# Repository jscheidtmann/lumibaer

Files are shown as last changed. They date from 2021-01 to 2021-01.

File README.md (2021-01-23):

# lumibaer
Program for controlling a enhanced version of a Flötotto "Lumibär"

Status: in development

# Pimping the Lumibär

The Lumibär is ca. 40 cm high, formed like a bear and was originally was designed and developed by FLÖTOTTO (AFAICT) with a 12V halogen light. Nowadays, a LED-version is sold with a remote, which allows to set the color. 

As we wanted to have a rather unique version, I set out to create a rather nerdy version of it and am sharing my build here. 

Features:

* Uses an Arduino Nano with ESP8266 for WiFi connectivity (aka. Pretzelboard or NanoESP)
* Two Adafruit 16 Neopixel Rings for blinkenlights
* A button was added to enable a hands-on on/off and color selection.
* Supports various different modes:
    * **Single color mode**: acts as a normal light, with a color of your choosing.
	* **Sweep mode**: Transition between two colors.
	* **Lighthouse mode**: Turn your Lumibär into your favourite lighthouse by entering the ligth characteristic.
	* Optionally use different front and back colors.
	
As our Lumibär is opaque white, we refrain from supporting movements or using single LED patterns. 

# Circuitry

The parts used:

| Count | Part | Comment |
|---|---|---|
| 1x | NanoESP | aka Pretzelboard, an Arduino Nano + ESP8266 on a single PCB |
| 2x | 16 Neopixel Ring | WS2812B, must fit through hole in bottom |
| 1x | Button Switch | color to your liking |
| 1x | 470Ω Resistor | recommended by Adafruit in Neopixel tutorial |
| 1x | 1000 µF Capacitator | recommended by Adafruit in Neopixel tutorial | 
| 1x | Power Supply | 5V output, at least 2A |
| 5x | Dupont terminals | for connecting wires with the Arduino |
| | cable binders | fixing the power cable |
| | heat-shrink tubing  | avoid short circuits |

The parts are connected like this:

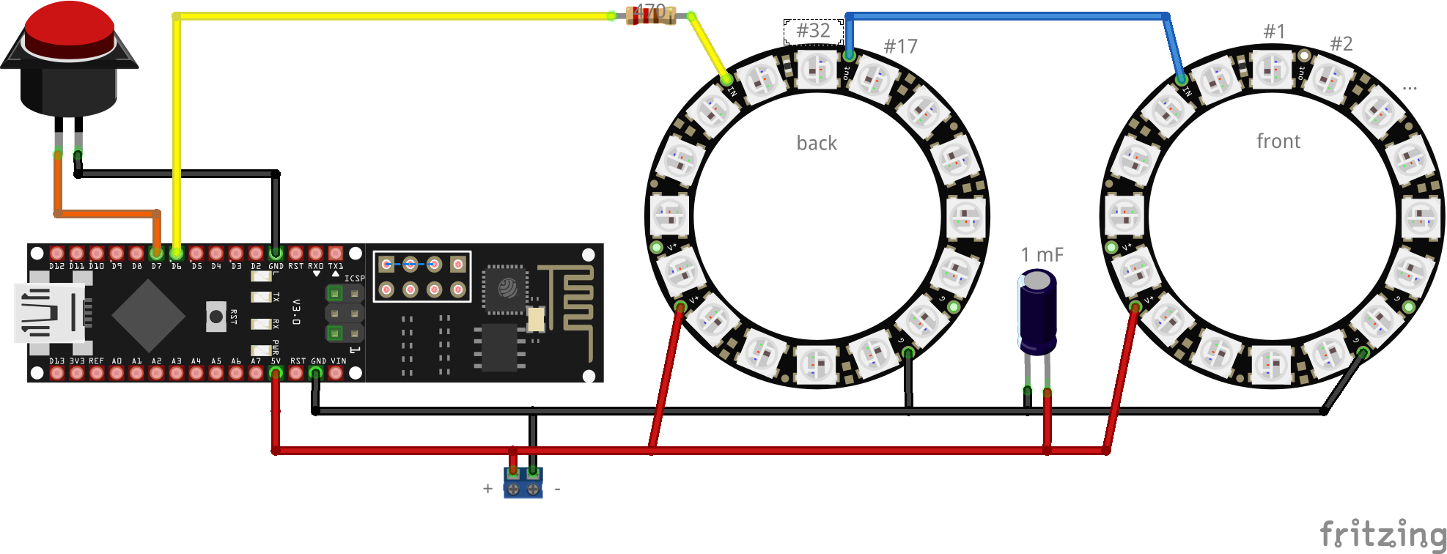
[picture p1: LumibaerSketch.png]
Fritzing circuit diagram Fritzing Circuit Diagram for Lumibär


Notes:

* The power supply has to be connected to the "screw terminal" at the bottom of the sketch
* The capacitator prevents damaging the pixel through the first current onrush, when the device is powered.
* The resistor prevents damaging the first pixel by spikes on the data line
* Both previous measure have been recommended in the [Adafruit Neopixel Überguide](https://learn.adafruit.com/adafruit-neopixel-uberguide/basic-connections)
* LED numbering implies how to mount the pixel rings in the holder (see below - lowest numbered pixel at top position), if you mount them differently, you may have to change some code.

--- W A R N I N G ---

When programming the Lumibaer, first power the device using the power supply, then connect the USB. If all 32 LEDs are set to full white, each LED draws approximately 60 milliamps, so in total a current of 1.9A is drawn, which is a) more than the Arduino is able to deliver and which b) might be more than the USB port of your computer is able to sustain. You have been warned!

# Holder

I 3D-printed the holder from white PLA on a Flashforge Finder. You can find the design at [onshape.com](https://cad.onshape.com/documents/3edbe17af1ac7154b36a21e5/w/be9cdfd852b25ba857e68c3f/e/f320dc2e18de69cdc695974b), the STL is also part of this repository. 

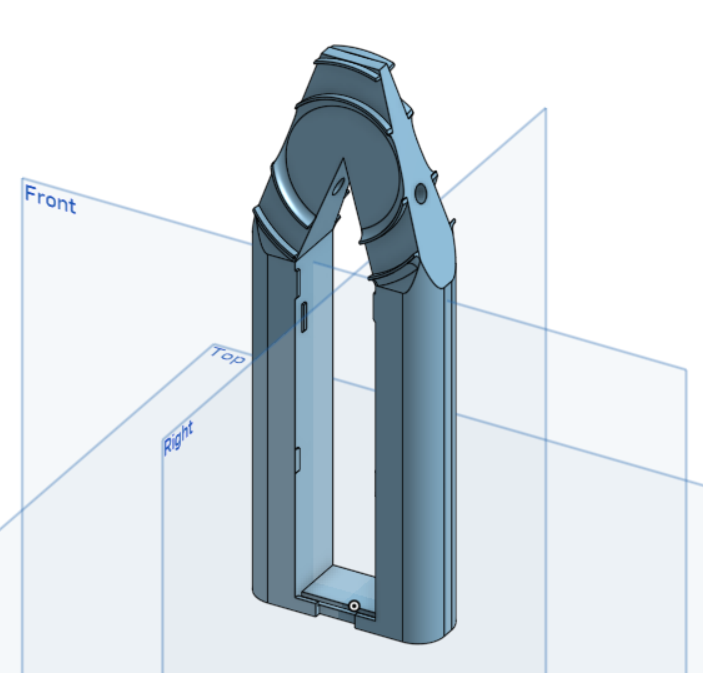
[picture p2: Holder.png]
Holder for Lumibaer isoscale rendering of the holder from onshape


Make sure that your printer's tolerances match your parts. In order to do this, print some prototypes to see, if:

1) The part fits on the metal rods holding it inside the Lumibär. Print the lowest 1 cm of the model. 
2) The Neopixel Rings fit into the holder (you have to press slightly, to get them in and fixed). Print the top part of the model.
3) Also check that the NanoESP fits into the middle opening (see below)

Only then print the full model

If scaling the model does not work and you need to change the design, here are some hints:

* The size of the holes (where the metal rods go) is in "Skizze 1"
* The circles defining the shape, where the Neopixel-rings go are defined in "Skizze 7".

# Assembly Instructions

1) Press in the two Neopixel-rings onto the holder, so that all terminals are still accessible and you can solder the wires
2) Put in the Arduino into the holder by inserting the ESP end at the top between the two protrusions, then force press it into place between the two sides. You may want to use a cutter knive to remove some of the protusions, so that it's easier to insert the Arduino
3) Solder the resistor onto the back facing D_IN port
4) Cut the power cord (5V) coming from the power supply and solder the capacitator in between the wires. Watch for the correct polarity, if you're using an electrolyte capacitator
5) Solder further power cables onto the pins of the capacitator
6) Prevent short circuits by using heat-shrink tubing
7) Fix the power cord to one of the metal rods using cable binders. Fix it two times, leaving some extra wire for protection against pulling out the wire.
8) Solder the remaining wires to the neopixel rings, using the holes in the holder for routing wires.
9) Attach Dupont-terminals to the wires going to be connected to the Arduino
10) Connect the wires to the Arduino
11) Connect the Arduino to your PC using an USB cable
12) If your Arduino features a blue power led, you should remove it (optional)

# Library Installations & Tests & Software Installation

Install the `Adafruit Neopixel` Library into your Arduinno IDE using the Tools -> Manage Libraries ... menu entry. For controlling the ESP part, download the [NanoESP library](https://iot.fkainka.de/library) (German site) or directly from [GitHub](https://github.com/FKainka/NanoESP).

In order to be able to upload sketches to the NanoESP, I had to choose Board "Arduino Nano" and Processor "ATmega328P (old bootloader)". You might need to choose a different setting, depending on how old your NanoESP is or wether your updated the firmware.

Then open and run the "strandtest" example from File -> Examples -> Adafruit NeoPixel. It should work out of the box. If it doesn't, check if the D_IN is connected to the right pin in the Arduino. You can then open the "test.ino" sketch from this project. It is basically a modified version of the strandtest program, which in addition switches the onboard LED, whenever the button switch is pressed and reorders the leds in the strip to make it easier to program later on. Check that the front ring is run through clockwise and back ring is run through conter clockwise. If that is not the case, check `pinTranslate()`.

If all is working well, define your network credentials in `credentials.h` and then compile and upload the `lumibaer.ino` sketch.

# Manual

## Initial State

When the Lumibär is connected to power, it tries to connect to the local WiFi, that you configured. If this is successful, the Lumibär flashes once in green. If it was unsuccessful, it flashes once in red. 

## Using the button

Pressing the button shortly switches the Lumibär on or off. The initial color is White (at full brightness). 
When switching on, hold the button and the Lumibär will cycle through colors. Just release the button, if the color is to your liking. After a color is selected, press the button shortly to switch the Lumibär on or off.

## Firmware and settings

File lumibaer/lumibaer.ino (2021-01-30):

/**
 * Lumibaer
 * 
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
 * 
 */

// Blinkenlights ---------------------------------------------

#include <Adafruit_NeoPixel.h>

// Which pin on the Arduino is connected to the NeoPixels?
#define LED_PIN    6

// How many NeoPixels are attached to the Arduino?
#define LED_COUNT 32

// Declare our NeoPixel strip object:
Adafruit_NeoPixel strip(LED_COUNT, LED_PIN, NEO_GRB + NEO_KHZ800);
// Argument 1 = Number of pixels in NeoPixel strip
// Argument 2 = Arduino pin number (most are valid)
// Argument 3 = Pixel type flags, add together as needed:
//   NEO_KHZ800  800 KHz bitstream (most NeoPixel products w/WS2812 LEDs)
//   NEO_KHZ400  400 KHz (classic 'v1' (not v2) FLORA pixels, WS2811 drivers)
//   NEO_GRB     Pixels are wired for GRB bitstream (most NeoPixel products)
//   NEO_RGB     Pixels are wired for RGB bitstream (v1 FLORA pixels, not v2)
//   NEO_RGBW    Pixels are wired for RGBW bitstream (NeoPixel RGBW products)

/**
 * Translate pin 
 */
int pinTranslate(int pin) {
  const int translation [] = { 
    // Front Ring, starting from 12 o'clock position, clockwise
    29, 28, 27, 26, 25, 24, 23, 22,  
    21, 20, 19, 18, 17, 16, 31, 30,
    // Back Ring, starting from one next to 12 o'clock position, counter clockwise
    13, 14, 15,  0,  1,  2,  3,  4,  
     5,  6,  7,  8,  9, 10, 11, 12, 
  };

  return translation[pin];
}


// ESP WiFi / Server Lib ---------------------------------------------------

// This is the library supplied by F. Kainka with the Pretzel Board. It is rather old and HTTP is rather limited.
#include <NanoESP.h>
#include <NanoESP_HTTP.h>

/**
 * define two string constants: 
 * WIFI = SSID of your router 
 * PASSWORD
 */
#include "credentials.h"

NanoESP nanoesp = NanoESP();
NanoESP_HTTP http = NanoESP_HTTP(nanoesp); 

// LED & Switch ------------------------------------------------------------

// Standard onboard LED on an Arduino Nano
#define ONBOARD_LED 13

// The switch button is connected to which pin?
#define SWITCH 7

// Switch Press must be detected this many milliseconds at least, to count as press.
#define SWITCH_THRESHOLD 50 

// Long press must be at least this long
// (should be at least two times SWITCH_THRESHOLD, see buttonDownDetected() )
#define SWITCH_LONGTHRESHOLD 2000

// Increment applied, when changing colors. 
// This is a prime on purpose.
#define SINGLE_INCREMENT 51

// Time (ms) waited when rotating colors
// (default value)
#define ROTATE_WAIT 50

// Time (ms) for Morse wait
// Short (.) = this time, long (-) = 3x this time.
// applies also to breaks between . and -, and words (long)
#define MORSE_WAIT 300

// Default Brightness 0-255
#define DEFAULT_BRIGHTNESS 50

// Globals -----------------------------------------------------------------

/**
 * Variable to enable debug output on the serial monitor.
 */
boolean debug_out = true;

/**
 * last time, a button down was detected
 * 
 * This variable is used to detect user interactions (presses of the button)
 */
unsigned long last_time = 0L;

/**
 * State of the button
 * 
 * T if button is pressed, F otherwise. 
 */
boolean button_state = false;

/**
 * Color that is displayed in single mode
 * 
 * Use strip.Color(R,G,B) or relatives
 */
uint32_t single_color = 0;

/**
 * Colors for Front/Back mode: Front color
 */
uint32_t front_color = 0;

/**
 * Colors for Front/Back mode: Back color
 */
uint32_t back_color = 0;

/**
 * Colors for ROTATE_MODE: Left color
 */
uint32_t left_color = 0;

/**
 * Colors for ROTATE_MODE: Right color
 */
uint32_t right_color = 0;

/**
 * Colors for sweep mode (back and forth): First color
 */
uint32_t sweep1 = 0;

/**
 * Colors for sweep mode (back and forth): Second color
 */
uint32_t sweep2 = 0;

/**
 * Colors for wave mode (up and down): Color to start with
 */
uint32_t wave1 = 0;

/**
 * Colors for wave mode (up and down): Color coming in and going out
 */
uint32_t wave2 = 0;

/**
 * Wait this many millisecond for a rotation step
 * 
 * Is set by "rotatewait" UDP command.
 * Smaller means quicker. 
 */
unsigned int rotate_wait = ROTATE_WAIT;

/**
 * State of rotation. 
 * 
 * Will be incremented, if one of the rotation modes is active.
 * (
 */
unsigned int rotate = 0;

/**
 * Which color is selected for Single color mode?
 * 
 * when running through colors, ie. button is long pressed.
 */
uint32_t single_hue = 0;

/**
 * The different modes supported by the Lumibaer software.
 */
enum modes {
  MODE_SINGLE_COLOR, // Show one color perpetually
  MODE_TWO_COLOR,    // Show different color on front and back.
  MODE_ROTATE_TWO,   // Show two colors on halves, then rotate.
  MODE_SWEEP,        // Sweep between two colors
  MODE_WAVE,         // Wave going up and down
  MODE_LIGHTHOUSE,   // Parse and show a lighthouse characteristic (Leuchtfeuer Kennung)
  MODE_MORSE,        // Show a Morse Code message.
  MODE_UNKNOWN
} lumibaer_mode = MODE_SINGLE_COLOR;

/**
 * Is Lumibär on or off?
 * 
 * For ALL modes
 */
boolean lumibaer_state = false;

/**
 * State for animations in modes: MODE_MORSE and MODE_LIGHTHOUSE
 */
struct animation_step {
  unsigned long duration;
  enum step_mode { 
    SINGLE, // 0
    TWO,    // 1
    THREE   // 3
  } mode;
  uint32_t color;
  uint32_t color2;
  uint32_t color3;
  int next;
} animation_steps[10];

int active_step = 0;


const String & morse_string = (String) NULL;
int morse_pos = 0;



// Network state -----------------------------------------------------------

/**
 * 
 */
boolean wifi_check_enabled = true;

boolean wifi_available = false;

boolean udp_server_running = false;

// setup() function -- runs once at startup --------------------------------

/**
 * Setup the Lumibaer
 * 
 * 1. Setup digital pins
 *     ONBOARD_LED: output, off
 *     SWITCH: input pullup
 *     
 * 2. Setup Neopixel rings/strip
 *     Set brightness to 50, to avoid Lumibaer`s head to get warm
 *     
 * 3. Default Mode: White, Single color mode
 * 
 * 4. Setup Serial (19200)
 * 
 * 5. Initialize NanoESP
 *     Does not yet setup the WiFi, this is done in the Main loop.
 *     
 * 6. Blink once in Blue, if setup worked 
 *     (Setup will not fail)
 */
void setup() {
  // Setup digital pins
  pinMode(ONBOARD_LED, OUTPUT);
  digitalWrite(ONBOARD_LED, false);
  pinMode(SWITCH, INPUT_PULLUP); // Has inverted logic (low = button pressed)

  // Setup Neopixel strip
  strip.begin();  // INITIALIZE NeoPixel strip object (REQUIRED)
  strip.show();   // Turn OFF all pixels ASAP
  strip.setBrightness(DEFAULT_BRIGHTNESS); // Set BRIGHTNESS (max = 255), is applied during strip.show()

  // Set Default Color
  single_color = strip.Color(255,255,255); // White
  lumibaer_mode = MODE_SINGLE_COLOR;

  // Set Default Lighthouse Mode 
  // Amrum Lighthouse (north sea): Fl. 6.5s
  animation_step * p = animation_steps;
  p->mode = animation_step::SINGLE;
  p->duration = 1000;
  p->next = 1;
  p->color = strip.Color(255,255,255); // White
  p++;
  p->mode = animation_step::SINGLE;
  p->duration = 5500;
  p->next = 0;
  p->color = strip.Color(0,0,0); // Black
  
  // Setup Serial
  if (debug_out) {
    // Serial.begin(9600);
    Serial.begin(19200); 
  }

  boolean setup_ok = true;
  
  // Setup ESP
  setup_ok = setup_ok && nanoesp.init();

  // Per default the ESP will connect to the WiFi once configured. 
  // It will take some time though. So setting it up is postponed to the loop.
  // In order to give an "immediately ready" feeling for the users.
  //
  // I tried waiting up to two seconds here, but it seems it can take longer.   

  // Indicate state of setup 
  if (setup_ok) { // If successful, blink ...
    colorFlash(strip.Color(0, 0, 255), 200); // Blue is ok (for color blind)
    debug(F("Setup: Ok"));
  } else {
    colorFlash(strip.Color(255, 0, 0), 200); // Red is bad
    debug(F("Setup: FAILED."));
  }
}

// loop() function -- runs repeatedly as long as board is on ---------------

/**
 * Main Loop
 * 
 * All waits are done using comparisons against "now", which is initialized at the start of the loop.
 * wait() is never called.
 * 
 * This is the order in which things are done:
 *  1.) Check state of the button. 
 *       Do we have a short press? -> Switch Lumibaer on/off
 *       Do we have a long press? -> Cycle colors
 *       Synchronize the onboard LED with the button press.
 *       
 *  2.) Setup the WiFi 
 *       Connect to the WiFi.
 *          Checks after 1s, if connect was successful. 
 *          If successful, flash green, if not successful, flash red.
 *          After 10 times, the connect is retried and a yellow flash occurs.
 *       If successful start a UDP server.
 *       
 *  3.) Handle UDP commands to the Lumibaer.
 *      The routine knows the following commands:
 *       "on", "off": 
 *          Switch Lumibaer on or off remotely
 *       "toggle":
 *          If Lumibaer is on, set it to off and vice versa
 *       "brightness?<x>": 
 *          Set brightness of NeoPixel strip. 
 *          <x> a number between 0 and 255, 
 *          if x is negative the default brightness will be set.
 *       "color?ffddee":
 *          Set color for single color mode. Pass the RGB colors as HTML color code (without "#")
 *          Switches to MODE_SINGLE and the Lumibaer on.
 *       "lighthouse?Oc(3) 5s RGW":
 *          Turns on lighthouse mode. Parses a lighthouse's characteristic into animation_steps, 
 *          see https://en.wikipedia.org/wiki/Light_characteristic 
 *       "morse?sos":
 *          Turns on Morse code mode. Parses a string into animation_steps, using Morse Code. 
 *          see https://en.wikipedia.org/wiki/Morse_code
 *       "rotate?ffddee,aabbcc":   
 *          half of the ring is color "ffddee", other half of ring is "aabbcc", as HTML color code.
 *          Switches to MODE_ROTATE_TWO and the Lumibaer on.
 *       "sweep?ffddee,aabbcc":
 *          Change color from ffddee to aabbcc, interpolating linearly for each color channel.   
 *          Siwtches to MODE_SWEEP and the Lumibaer on.
 *       "two?ffddee,aabbcc":
 *          Set color for two color mode (Front and Back different color)
 *          Pass the two colors as RGB colors (replacing ffddee and aabbcc with respective values).
 *          Switches to MODE_TWO_COLOR and the Lumibaer on.
 *       "wave?ffddee,aabbcc":
 *          Start with color ffddee (HTML RGB code, leave out the "#". 
 *          then let other color aabbcc swell up and down like a wave
 *          
 * 4.) Handle Animation
 *       If a mode needs animation and is active, the rotation variable is increased 
 *       and the strip state is synchronized.
 *           
 */
void loop() {
  static unsigned long last_rotate = 0L;
  unsigned long now = millis();

  /////////////////////////////////////////////////////////////////////////////////  
  // Step 1.)
  // Handle Button Presses (Switches to MODE_SINGLE_COLOR)
  
  if (buttonDownDetected(now)) {
    // Handle button press (on/off)
    lumibaer_state = !lumibaer_state; // toggle on/off
    synchronizeStrip();
  }
  
  if (longPressDetected(now) && lumibaer_mode == MODE_SINGLE_COLOR) {
    single_hue += SINGLE_INCREMENT;
    single_color = strip.gamma32(strip.ColorHSV(single_hue));
    synchronizeStrip();
    delay(10);
  } 

  // Make onboard LED reflect button state.
  onboardLedSwitch();

  /////////////////////////////////////////////////////////////////////////////////  
  // Step 2.)
  // Try setting up the WiFi (once a second)
  static unsigned long last_check = 0L;
  static int wifi_check_count = 0;
  
  if (wifi_check_enabled && (now - last_check) > 1000L) {
    wifi_check_count++;
    String response = nanoesp.getIp();
    if (-1 == response.indexOf("0.0.0.0")) {
      wifi_check_enabled = false;
      wifi_available = true;
      debug(response);
      debug(String(wifi_check_count));
      colorFlash(strip.Color(0, 255, 0), 50); // Green
    } else {
      last_check = now;
      if (wifi_check_count > 10) {
        colorFlash(strip.Color(0,255,255), 50); // yellow
        // connect to WiFi
        nanoesp.configWifi(STATION, WIFI, PASSWORD);
        // Enable Autoconnection (saves to ESP flash). 
        // Once done, it should auto set up, during the 10 seconds wait time,
        // so we never get here again.
        nanoesp.sendCom("AT+CWAUTOCONN=1"); 
        wifi_check_count = 0;
      } else {
        colorFlash(strip.Color(255,0,0), 50); // Red
      }
    }
  }

  if (wifi_available && !udp_server_running) {
    if (nanoesp.startUdpServer(0,"192.168.178.255", 8888,8888,2)) {
      udp_server_running = true;
      debug(F("UDP server started."));
    } else {
      debug(F("FAILURE starting UDP server."));
    }
  }

  /////////////////////////////////////////////////////////////////////////////////
  // Step 3.) Serve UDP Commands
  
  // / * // Comment out Step 3, for passthrough, see below
  int client, len; 
  while (nanoesp.recvData(client, len)) {
    String request = nanoesp.readString();
    debug("recv:"); debug(request);
    if (request.startsWith(F(":on"))) {
      lumibaer_state = true;
      // debug(F("Set ON!"));
    } else if (request.startsWith(F(":off"))) {
      lumibaer_state = false;
      // debug(F("Set OFF!"));
    } else if (request.startsWith(F(":brightness?"))) {
      // debug(F("brightness"));
      int brightness = strtol(request.substring(12).c_str(), NULL, 10);
      if (brightness < 0) brightness = DEFAULT_BRIGHTNESS;
      if (brightness > 255) brightness = 255;
      strip.setBrightness(brightness);
    } else if (request.startsWith(F(":rotwait?"))) {
      // debug(F("rotwait"));
      rotate_wait = strtoul(request.substring(9).c_str(), NULL, 10);
      // Avoid values that are two small. 
      if (rotate_wait < 100) rotate_wait = 100;
    } else if (request.startsWith(F(":toggle"))) {
      lumibaer_state = !lumibaer_state;
      // debug(F("Toggle!"));
    } else if (request.startsWith(F(":color?"))) {
      lumibaer_mode = MODE_SINGLE_COLOR;
      // debug(request.substring(7,13));
      uint32_t color = strtoul(request.substring(7,13).c_str(),NULL, 16);
      lumibaer_state = true;
      single_color = color;
      debug(F("Single color set"));
    } else if (request.startsWith(F(":two?"))) {
      lumibaer_mode = MODE_TWO_COLOR;
      lumibaer_state = true;
      // debug(F("TWO"));
      // debug(request.substring(5,11));
      // debug(request.substring(12,18));
      front_color = strtoul(request.substring(5, 11).c_str(), NULL, 16);
      back_color = strtoul(request.substring(12,18).c_str(), NULL, 16);
    } else if (request.startsWith(F(":rotate?"))) {
      lumibaer_mode = MODE_ROTATE_TWO;
      lumibaer_state = true;
      rotate = 0;
      left_color = strtoul(request.substring(8, 14).c_str(), NULL, 16);
      right_color = strtoul(request.substring(15,21).c_str(), NULL, 16);
    } else if (request.startsWith(F(":sweep?"))) {
      lumibaer_mode = MODE_SWEEP;
      lumibaer_state = true;
      rotate=0;
      sweep1 = strtoul(request.substring(7, 13).c_str(), NULL, 16);
      sweep2 = strtoul(request.substring(14, 20).c_str(), NULL, 16);
    } else if (request.startsWith(F(":lighthouse?"))) {
      lumibaer_mode = MODE_LIGHTHOUSE;
      lumibaer_state = true;
      rotate=0;
      parseLighthouseSpec(request.substring(12));
    } else if (request.startsWith(F(":morse?"))) {
      lumibaer_mode = MODE_MORSE;
      lumibaer_state = true;
      rotate=0;
      parseMorseSpec(request);
      last_rotate = 0L;
    } else if (request.startsWith(F(":wave?"))) {
      lumibaer_mode = MODE_WAVE;
      lumibaer_state = true;
      rotate=0;
      wave1 = strtoul(request.substring(6, 12).c_str(), NULL, 16);
      wave2 = strtoul(request.substring(13, 19).c_str(), NULL, 16);
    }
    synchronizeStrip();
  }

  /////////////////////////////////////////////////////////////////////////////////  
  // Step 4.) Handle animations
  if (lumibaer_state) {
    // Lumibaer needs to be on.
    switch (lumibaer_mode) {
      case MODE_ROTATE_TWO:
      case MODE_SWEEP: 
      case MODE_WAVE:
        if (last_rotate == 0L) {
          last_rotate = now; 
        } else if ((now - last_rotate) > rotate_wait) {
          last_rotate = now;
          // debug(F("rotate"));
          rotate++;
          synchronizeStrip();
        }
        break;
      case MODE_LIGHTHOUSE:
      case MODE_MORSE:
        if (last_rotate == 0L) {
          last_rotate = now;
          active_step = 0;
          // switch on immediately:
          synchronizeStrip();
          rotate_wait = animation_steps[active_step].duration;
        } else if ((now - last_rotate) > rotate_wait) {
          last_rotate = now;
          active_step = animation_steps[active_step].next;
          if (active_step < 0) 
            nextMorseCharacter();
          synchronizeStrip();
          rotate_wait = animation_steps[active_step].duration;
        }
      default: 
        ; // No Op
        break;
    }    
  }
  // */ // Comment out step 3
  /*
  //////////////////////////////////////////////////////////////////////
  // Pass input from Serial through to the NanoESP. 
  // 
  // !!! To avoid clashes with UDP command handling, you need to comment out Step 3!!!
  // Serial Monitor passes stuff through to the ESP.
  while (Serial.available()) {
    nanoesp.write(Serial.read());
    delay(10);
  } 
  while (nanoesp.available()) {
    Serial.write(nanoesp.read());
  } 
  */
}


// Lighthouse --------------------------------------------------------------

/**
 * Lighthouse modes.
 */
enum lh {
  FIXED,
  FLASH,
  LONG_FLASH, 
  OCCULTING,
  ISO,
  QUICK,
  VERYQUICK
} lh_m = lh::FIXED; 

int lh_groups = 1;

struct lh_color {
  char color_ch; 
  uint32_t color;
} lh_colors[] = { 
  { 'W', strip.Color(255,255,255) },
  { 'R', strip.Color(255,  0,  0) },
  { 'G', strip.Color(  0,255,  0) },
  { 'B', strip.Color(  0,  0,255) },
  { 'Y', strip.Color(  0,255,255) }
};

int lh_cycle = 0; // Cycle time in ms, e.g. 6500 for 6.5s.

String lh_colspec = (String) NULL;

/**
 * Oc(2)WRG.9s
 * 
 * BNF of a Lighthouse characteristic, see https://en.wikipedia.org/wiki/Light_characteristic
 * 
 * characteristic = mode group? color? cycle? .
 * mode           = "F" | "Iso" | "Fl" group? | "L.Fl" group? | "Oc" group? | "Q" group? | "VQ" group? .  
 *   // No group and cycle for "F". 
 *   // No cylce for "Q" and "VQ" when standalone, but if a group is specified, it becomes mandatory.
 * group          = "(" posnumber ")" .  
 * color          = colcode+ .
 * colcode        = "W" | "R" | "G" | "B" | "Y" . 
 * cycle          = float "s" .
 * float          = posnumber+ ( "." number+ )? .    // Note: we use one of the string to number functions, so you can ignore the rest of the spec.
 * posnumber      = notnull number* .
 * notnull        = "1" | "2" | "3" | "4" | "5" | "6" | "7" | "8" | "9" . 
 * number         = "0" | notnull .
 * 
 * Note: US light characteristic listing at http://uslhs.org uses a different way of specifying the characteristic.
 * 
 * Durations:
 *    L.Fl = 3s on per L.Fl
 *    Oc + F = 1s on per Flash
 *    Q = 1 "on" per Second (500 ms)
 *    VQ = 2x "on" per Second (250 ms)
 * 
 * Some Examples: 
 *              Amrum: Fl 6.5s 
 *          Helgoland: Fl 5s
 *       Süderoogsand: Iso WR 6s
 *    Westerheversand: Oc(3) WRG 15s
 *     Folkstone (UK): Fl(2) 10s
 *       Danger North: Q
 *       Danger South: Q(6)+L.Fl 15s  <<== TODO: Cannot be done with this parser.
 *        Danger East: Q(9)15s
 *        Danger West: Q(3)15s
 *     (Danger signs can also be VQ instead of Q)
 */
void parseLighthouseSpec(const String & spec) {
  // Remove old state
  lh_colspec = "";
  
  int pos = 0;

  // Only use a single line: 
  spec = spec.substring(0, spec.indexOf("\n"));
  debug(F("parseLightHouseSpec"));
  debug(spec);
  if (!parse_lh_mode_group(spec, pos)) {
    debug(F("Wrong Mode"));
    return;
  }
  debug(String(pos));
  debug(F("mode_group ok"));
  if (!parse_lh_colors(spec,pos)) {
    debug(F("Wrong colspec"));
    return;
  }
  debug(String(pos));
  debug(F("colors ok"));
  if (!parse_lh_cycle(spec,pos)) {
    if (lh_m == lh::FIXED || lh_m == lh::QUICK || lh_m == lh::VERYQUICK) {
      lh_groups=1;
      if (lh_m == lh::QUICK) {
        lh_cycle = 500*2;        
      } else if (lh_m == lh::VERYQUICK) {
        lh_cycle = 250*2;
      }
    } else {
      debug(F("Wrong cycle spec"));
      return;
    }
  }
  debug(String(pos));
  debug(F("cycle ok"));
  
  // / *
  debug(F("*** Parse Result: mode, colspec, groups, cycle (ms)"));
  debug(String(lh_m));
  debug(lh_colspec);
  debug(String(lh_groups));
  debug(String(lh_cycle));
  // */ 

  compile_lh();

  dump_animation();
}

void dump_animation() {
  debug(F("************* Dump animation **********"));
  for (int i = 0; i < sizeof(animation_steps)/sizeof(animation_step); i++) {
    animation_step s = animation_steps[i];
    debug(F("*** #, mode, duration, next, col, col2, col3"));
    debug(String(i));
    debug(String(s.mode));
    debug(String(s.duration));
    debug(String(s.next));
    debug(String(s.color, 16));
    debug(String(s.color2, 16));
    debug(String(s.color3, 16));
  }
}
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

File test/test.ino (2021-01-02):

// A basic everyday NeoPixel strip test program.

// NEOPIXEL BEST PRACTICES for most reliable operation:
// - Add 1000 uF CAPACITOR between NeoPixel strip's + and - connections.
// - MINIMIZE WIRING LENGTH between microcontroller board and first pixel.
// - NeoPixel strip's DATA-IN should pass through a 300-500 OHM RESISTOR.
// - AVOID connecting NeoPixels on a LIVE CIRCUIT. If you must, ALWAYS
//   connect GROUND (-) first, then +, then data.
// - When using a 3.3V microcontroller with a 5V-powered NeoPixel strip,
//   a LOGIC-LEVEL CONVERTER on the data line is STRONGLY RECOMMENDED.
// (Skipping these may work OK on your workbench but can fail in the field)

#include <Adafruit_NeoPixel.h>

// Which pin on the Arduino is connected to the NeoPixels?
// On a Trinket or Gemma we suggest changing this to 1:
#define LED_PIN    6

// How many NeoPixels are attached to the Arduino?
#define LED_COUNT 32

// Declare our NeoPixel strip object:
Adafruit_NeoPixel strip(LED_COUNT, LED_PIN, NEO_GRB + NEO_KHZ800);
// Argument 1 = Number of pixels in NeoPixel strip
// Argument 2 = Arduino pin number (most are valid)
// Argument 3 = Pixel type flags, add together as needed:
//   NEO_KHZ800  800 KHz bitstream (most NeoPixel products w/WS2812 LEDs)
//   NEO_KHZ400  400 KHz (classic 'v1' (not v2) FLORA pixels, WS2811 drivers)
//   NEO_GRB     Pixels are wired for GRB bitstream (most NeoPixel products)
//   NEO_RGB     Pixels are wired for RGB bitstream (v1 FLORA pixels, not v2)
//   NEO_RGBW    Pixels are wired for RGBW bitstream (NeoPixel RGBW products)

// -------------------------------------------------------------------------

#define ONBOARD_LED 13
#define SWITCH 7

// setup() function -- runs once at startup --------------------------------

int pinTranslate(int pin) {
  const int translation [] = { 
    // Front Ring, starting from 12 o'clock position, clockwise
    29, 28, 27, 26, 25, 24, 23, 22,  
    21, 20, 19, 18, 17, 16, 31, 30,
    // Back Ring, starting from 12 o'clock position, counter clockwise
    14, 15,  0,  1,  2,  3,  4,  5,
     6,  7,  8,  9, 10, 11, 12, 13
  };

  return translation[pin];
}

void setup() {
  // These lines are specifically to support the Adafruit Trinket 5V 16 MHz.
  // Any other board, you can remove this part (but no harm leaving it):
#if defined(__AVR_ATtiny85__) && (F_CPU == 16000000)
  clock_prescale_set(clock_div_1);
#endif
  // END of Trinket-specific code.

  pinMode(ONBOARD_LED, OUTPUT);
  digitalWrite(ONBOARD_LED, false);
  pinMode(SWITCH, INPUT_PULLUP); // Has inverted logic (low = button pressed)

  strip.begin();           // INITIALIZE NeoPixel strip object (REQUIRED)
  strip.show();            // Turn OFF all pixels ASAP
  strip.setBrightness(50); // Set BRIGHTNESS to about 1/5 (max = 255)
}

//
// Copy the 
void onboardLedSwitch() {
  boolean val = digitalRead(SWITCH);
  digitalWrite(ONBOARD_LED, !val);
}

// loop() function -- runs repeatedly as long as board is on ---------------

void loop() {
  // Fill along the length of the strip in various colors...
  colorWipe(strip.Color(255,   0,   0), 50); // Red
  colorWipe(strip.Color(  0, 255,   0), 50); // Green
  colorWipe(strip.Color(  0,   0, 255), 50); // Blue

  // Do a theater marquee effect in various colors...
  theaterChase(strip.Color(127, 127, 127), 50); // White, half brightness
  theaterChase(strip.Color(127,   0,   0), 50); // Red, half brightness
  theaterChase(strip.Color(  0,   0, 127), 50); // Blue, half brightness

  rainbow(10);             // Flowing rainbow cycle along the whole strip
  theaterChaseRainbow(50); // Rainbow-enhanced theaterChase variant

  oneColorChase(strip.Color(255,255,255), 50);
  oneColorChase(strip.Color(255,  0,  0), 50);
  oneColorChase(strip.Color(  0,255,  0), 50);
  oneColorChase(strip.Color(  0,  0,255), 50);
}


// Some functions of our own for creating animated effects -----------------

// Fill strip pixels one after another with a color. Strip is NOT cleared
// first; anything there will be covered pixel by pixel. Pass in color
// (as a single 'packed' 32-bit value, which you can get by calling
// strip.Color(red, green, blue) as shown in the loop() function above),
// and a delay time (in milliseconds) between pixels.
void colorWipe(uint32_t color, int wait) {
  for(int i=0; i<strip.numPixels(); i++) { // For each pixel in strip...
    strip.setPixelColor(pinTranslate(i), color);         //  Set pixel's color (in RAM)
    strip.show();                          //  Update strip to match
    onboardLedSwitch();
    delay(wait);                           //  Pause for a moment
  }
}

// Theater-marquee-style chasing lights. Pass in a color (32-bit value,
// a la strip.Color(r,g,b) as mentioned above), and a delay time (in ms)
// between frames.
void theaterChase(uint32_t color, int wait) {
  for(int a=0; a<10; a++) {  // Repeat 10 times...
    for(int b=0; b<3; b++) { //  'b' counts from 0 to 2...
      strip.clear();         //   Set all pixels in RAM to 0 (off)
      // 'c' counts up from 'b' to end of strip in steps of 3...
      for(int c=b; c<strip.numPixels(); c += 3) {
        strip.setPixelColor(pinTranslate(c), color); // Set pixel 'c' to value 'color'
      }
      strip.show(); // Update strip with new contents
      onboardLedSwitch();
      delay(wait);  // Pause for a moment
    }
  }
}

// Rainbow cycle along whole strip. Pass delay time (in ms) between frames.
void rainbow(int wait) {
  // Hue of first pixel runs 5 complete loops through the color wheel.
  // Color wheel has a range of 65536 but it's OK if we roll over, so
  // just count from 0 to 5*65536. Adding 256 to firstPixelHue each time
  // means we'll make 5*65536/256 = 1280 passes through this outer loop:
  for(long firstPixelHue = 0; firstPixelHue < 5*65536; firstPixelHue += 256) {
    for(int i=0; i<strip.numPixels(); i++) { // For each pixel in strip...
      // Offset pixel hue by an amount to make one full revolution of the
      // color wheel (range of 65536) along the length of the strip
      // (strip.numPixels() steps):
      int pixelHue = firstPixelHue + (i * 65536L / strip.numPixels());
      // strip.ColorHSV() can take 1 or 3 arguments: a hue (0 to 65535) or
      // optionally add saturation and value (brightness) (each 0 to 255).
      // Here we're using just the single-argument hue variant. The result
      // is passed through strip.gamma32() to provide 'truer' colors
      // before assigning to each pixel:
      strip.setPixelColor(pinTranslate(i), strip.gamma32(strip.ColorHSV(pixelHue)));
    }
    strip.show(); // Update strip with new contents
    onboardLedSwitch();
    delay(wait);  // Pause for a moment
  }
}
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

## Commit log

2021-01-01 Added Fritzing Sketch
    [LumibaerSketch.fzz]
2021-01-01 Finalized Fritzing Sketch
    [LumibaerSketch.fzz]
2021-01-02 First working version: Button switches on/off and changes color.
2021-01-02 Added usage info for button.
2021-01-05 Updated Fritzingsketch, to reflect final pinTranslate()
    [LumibaerSketch.fzz]
2021-01-23 Remove Power LED step added to assembly instructions.
2021-01-30 Fixing the bug introduced with second last commit: Groupings now work again for lighthouse mode.
    [lumibaer.ino]
2021-12-28 Added simple UI using kivy for Raspberry Pi + Touchscreen

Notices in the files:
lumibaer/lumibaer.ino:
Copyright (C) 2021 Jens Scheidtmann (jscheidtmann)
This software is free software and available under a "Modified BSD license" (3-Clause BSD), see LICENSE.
